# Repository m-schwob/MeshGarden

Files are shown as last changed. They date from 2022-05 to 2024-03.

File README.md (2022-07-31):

# MeshGarden - repository content
The repository contains 3 main folder:
- MeshGardenApp - contains the source good of the android app (built using dart).
- Firbase - contains the source code for firebase cloud functions (written in javaScript).
- ESP - contains the source code for the hardware, ESP32/ESP8266 (written in c++ using arduino framework).

Other useful folders:
- utils - contain some useful code for development but not necessary.
- ESP/examples - contains some side code and example used to develop some of the code unit saperetly. great as code reference.

# MeshGarden - introduction

MeshGarden project is an iot system designed to monitor and maintain small and large scale gardens the system supports a verity of controllers. 
For now its designed to work on ESP8266 and ESP32
the system requires only one ESP32 micro controller to be connected to the Wi-Fi (bridge node) and can maintain many ESP8266 nodes that will take measurements 
from easy to custome sensors.
messages passes down from the sensors to the bridge node via local Mesh network,
the data passes from the bridge node to a firestore server and can be accessed and changed with a designated cell phone app.

# MeshGarden - system diagram

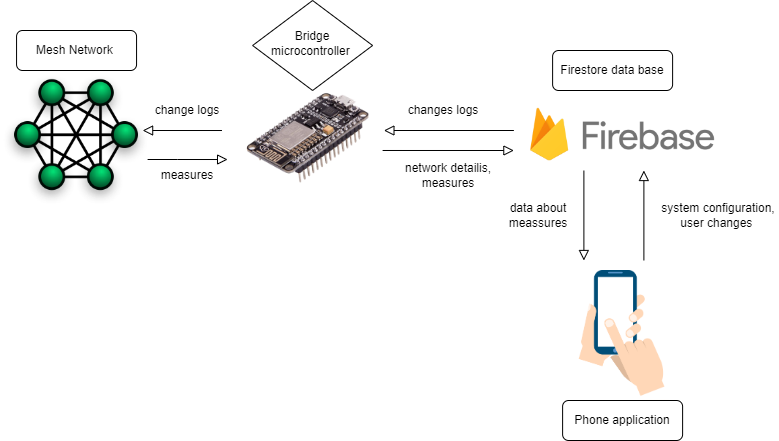
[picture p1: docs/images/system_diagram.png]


As explained, the system composed over 3 major parts: the mesh network , the firestore server and the MeshGarden application 
that are interconnected.

# MeshGarden - nodes life cycle

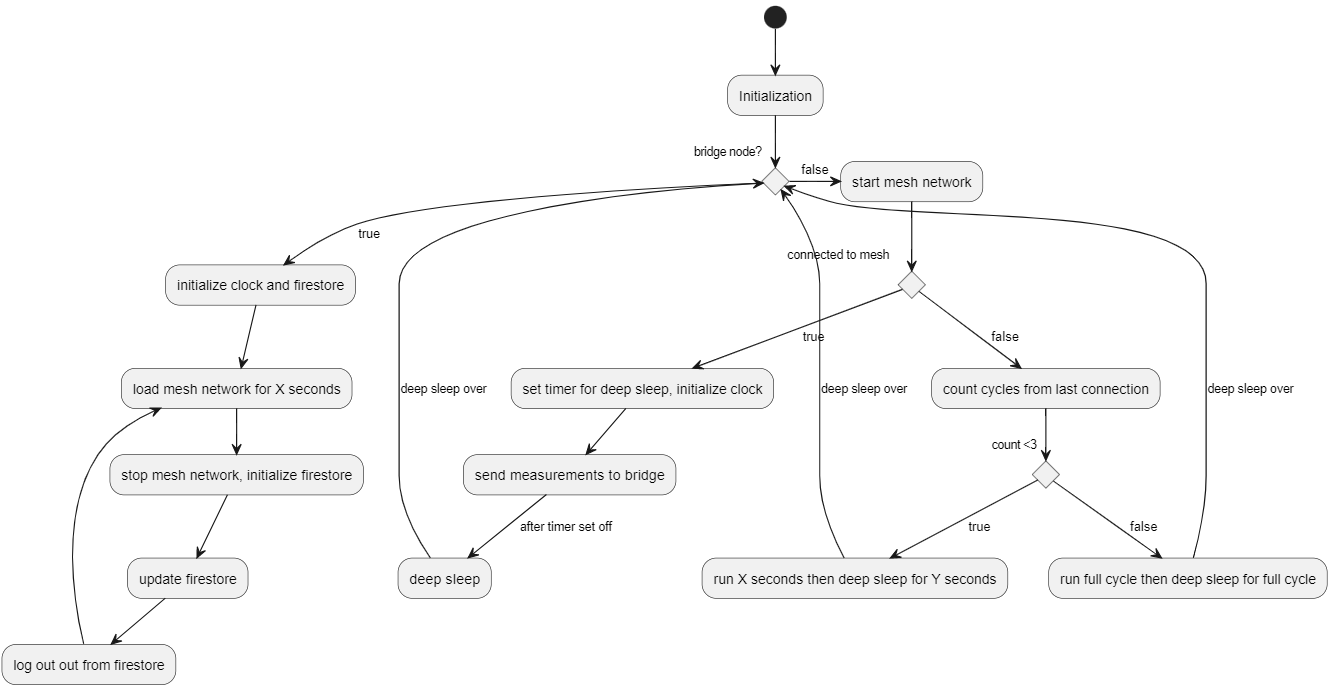
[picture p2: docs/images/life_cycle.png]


# MeshGarden - library dependency

* painlessmesh/painlessMesh@^1.5.0

* mobizt/Firebase Arduino Client Library for ESP8266 and ESP32 @ ^4.0.3

* bblanchon/ArduinoJson @ ^6.19.4

* adafruit/DHT sensor library@^1.4.3

* adafruit/Adafruit ADS1X15@^2.4.0

* me-no-dev/ESP Async WebServer @ 1.2.3

* fbiego/ESP32Time@^1.1.0

# MeshGardenAPP - library dependency
* cupertino_icons: ^1.0.2  
* firebase_auth: ^3.1.0   
* firebase_core: ^1.6.0   
* cloud_firestore: ^3.1.14  
* google_fonts: ^2.1.0    
* adaptive_dialog: ^1.1.0  
* font_awesome_flutter: ^10.1.0  
* chart_sparkline: ^1.0.5  
* intl: ^0.17.0  
* hawk_fab_menu: ^1.1.2  
* flutter_launcher_icons: ^0.9.0  
* charts_flutter: ^0.12.0  
* syncfusion_flutter_charts: 20.1.55  
* syncfusion_flutter_core: 20.1.55  

# MeshGarden - features
Mesh network features:

* Mesh networks allows the user to disperse the sensors over a larger area with no need to be in proximity to Wi-Fi AP
* The system allows the user to add its own costumize sensors easily by writing his own 2 functions
* Mesh networks creates stability, it has the ability to fix itself when a node is down  

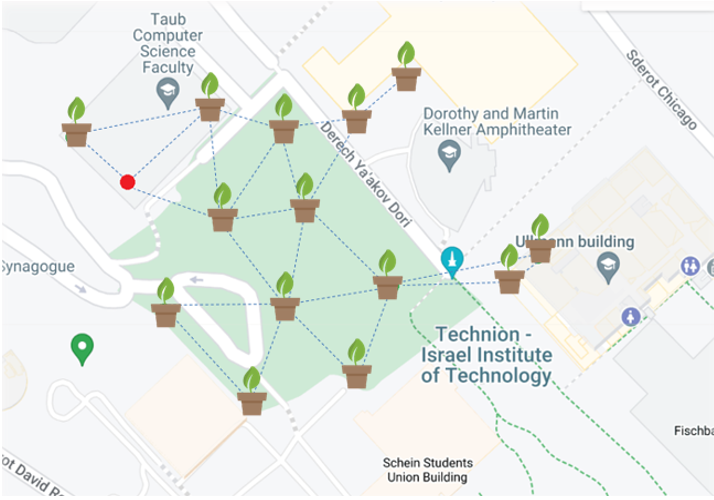
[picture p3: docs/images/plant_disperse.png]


Application features:

* Shows the active nodes in the network
* Change node nicknames of nodes in order to identify where they are located
* Configure new sensors to a node
* Presents the user the measurements of a selected node
* Present the user time series graph of the measures taken by a sensor
* Present the active nodes and their battery values to the user  

App screenshots:

 <table>
  <tr>
    <td>DHT22 Measurements</td>
     <td>UVi and Soli Moisture Measurements</td>
     <td>Time Series chart</td>
  </tr>
  <tr>
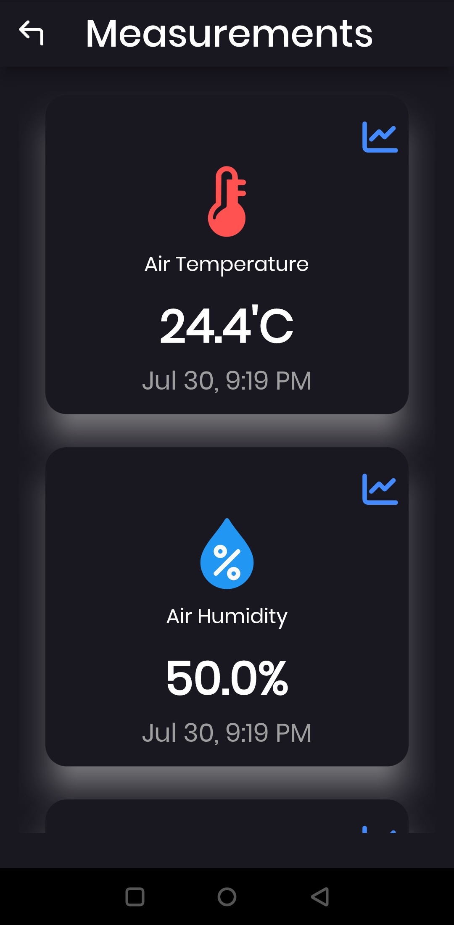
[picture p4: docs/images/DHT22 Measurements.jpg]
    <td valign="top"></td>
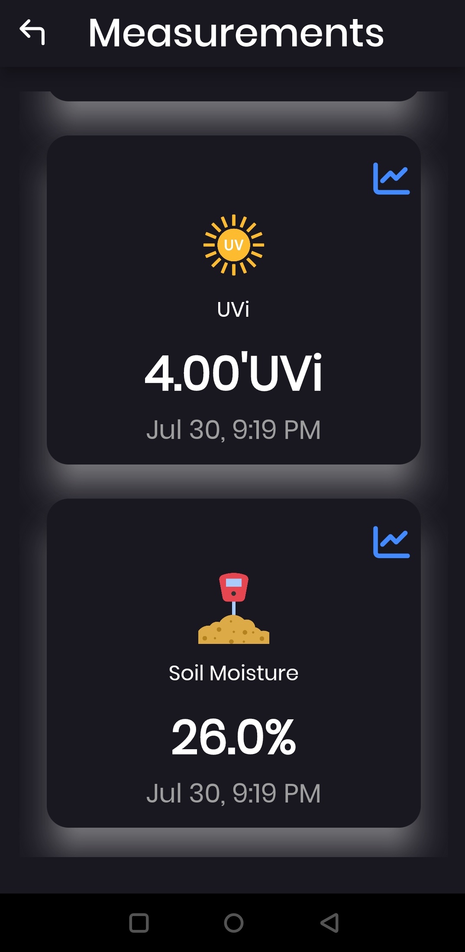
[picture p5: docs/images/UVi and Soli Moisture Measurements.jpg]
    <td valign="top"></td>
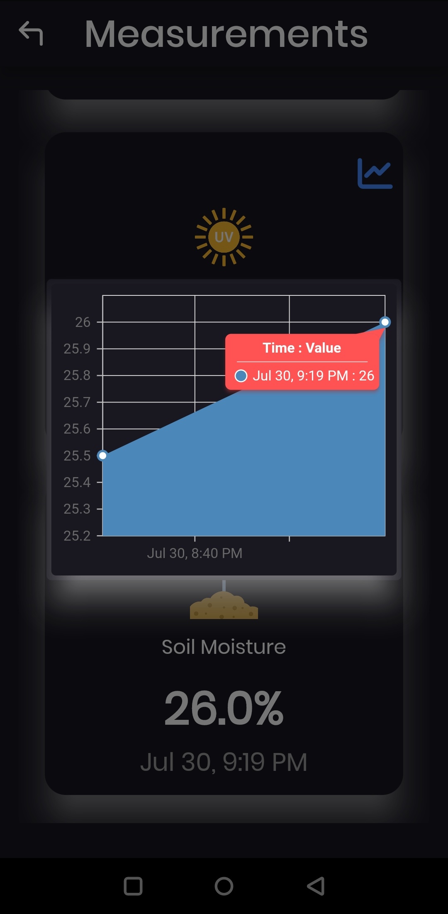
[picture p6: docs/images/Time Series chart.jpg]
    <td valign="top"></td>
  </tr>
 </table>

# MeshGarden - setup the system

## **step 1:** setup firebase server

follow the instruction in the videos bellow by "That Project" in order to setup your own firestore server

video 1:
set a firebase server https://www.youtube.com/watch?v=KV0D8nrsBLg&t=0s  
*TIP* : when choosing the cloud firestore location use the https://www.gcping.com 
site in order to find the server that provide the minimal latency 

video 2:
connect the firebase to the app https://www.youtube.com/watch?v=nsopdabOcug&t=3s   
*Note* : The files provided in the MeshGaredApp directory are source code *only*, so in order to use them,
create a new flutter project and follow the above video  

## **step 2:** create an account in the MeshGarden app with your own usermane and password

## **step 3:** assembly the micro controllers as shown bellow

## **step 4:** prepare the configure.json file

config json for example

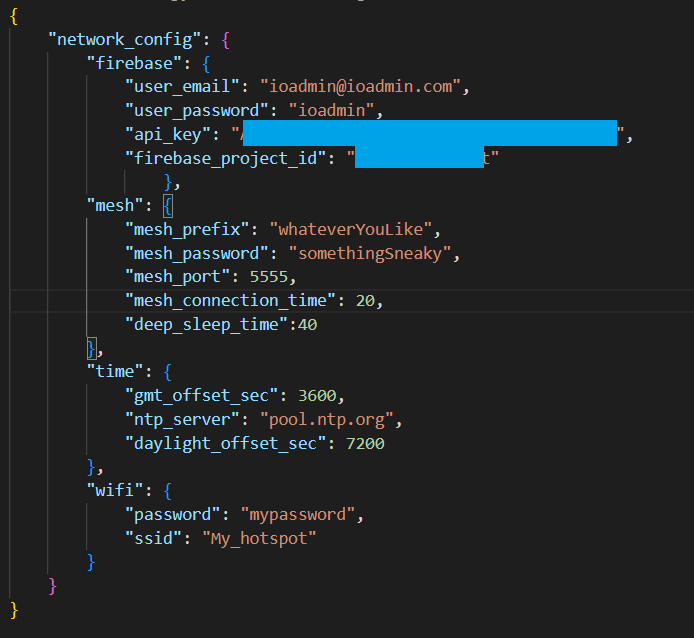
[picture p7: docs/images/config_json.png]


user_email,user_password - the username and password with whom you registered to the application
api_key - the unique key generated for your firebase server
firebase_project_id - the firebase progect id 

**mesh_prefix** - the SSID of the mesh network

**mesh_password** - the Password for the mesh network

**mesh_port** - a port the mesh network will run with

**mesh_connection_time** - the number of seconds within them the mesh network will run and be active (for battery saving for the nodes)

**deep_sleep_time** - the number of seconds withing them all the sensor nodes will go to deep sleep, in that time the bridge connects to the  internet and updates/read the changes from the database

**gmt_offset_sec,ntp_server,daylight_offset_sec**- values set in order to read the current time and make sure the nodes will store the current time in the user region/country

**ssid,password** - the local Wi-Fi ssid and password. Connects the bridge to the internet 

# MeshGarden - Hardware
## Basic Required Hardware

The system must contain at exactly one bridge (ESP32) and at least one node (ESP8266). The bridge is powered by fix power supply since its power consumption is high and can hold for long on battery. The nodes are powered by batteries and to be portable .

## Bridge Components and Assembly:
Components:
- ESP32 micro-controller module
- USB 4V 1A power adapter.
- LED + matched resistor (for example 1.8 green LED with 330ohm resistor)

> The LED use as indicator and connected in parallel to ESP32 module build in LED. So it can be skipped if the build in LED visible.

## Assembly:

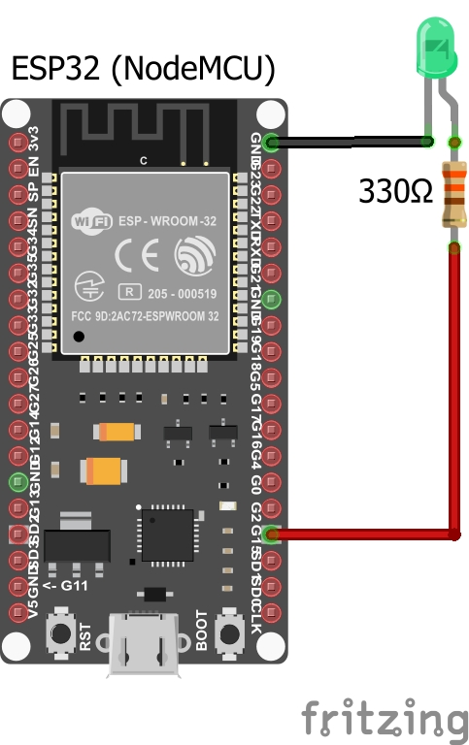
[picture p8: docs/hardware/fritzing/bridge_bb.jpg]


## Node Components and assembly:
Nodes can be assembled in many ways using any sensor. Some component are is required for the system operation and some are optional. The require components are listed in the *Basic Node Module* section below and the optional are exampled in the *Sensors Options* section.

### Basic Node Module
The below component are the base hardware of the node and required for its operations. 

Components:
- ESP8266 micro-controller module
- ADS1115 ADC expender module
- 3.7V lithium battery (2000mAh and greater is recommended)
- TP4056 lithium charging module
- MCP1700-3302E LDO 3.3V voltage regulator
- 100uF capacitor
- 1uF capacitor
- 36k resistor
- 100k resistor
- on/off switch
- NC switch or jumper 
- LED + matched resistor (for example 1.8 green LED with 330ohm resistor)

> all capacitor must be at least 5V rated.

> The LED use as indicator and connected in parallel to ESP8266 module build in LED. So it can be skipped if the build in LED visible.

Assembly:
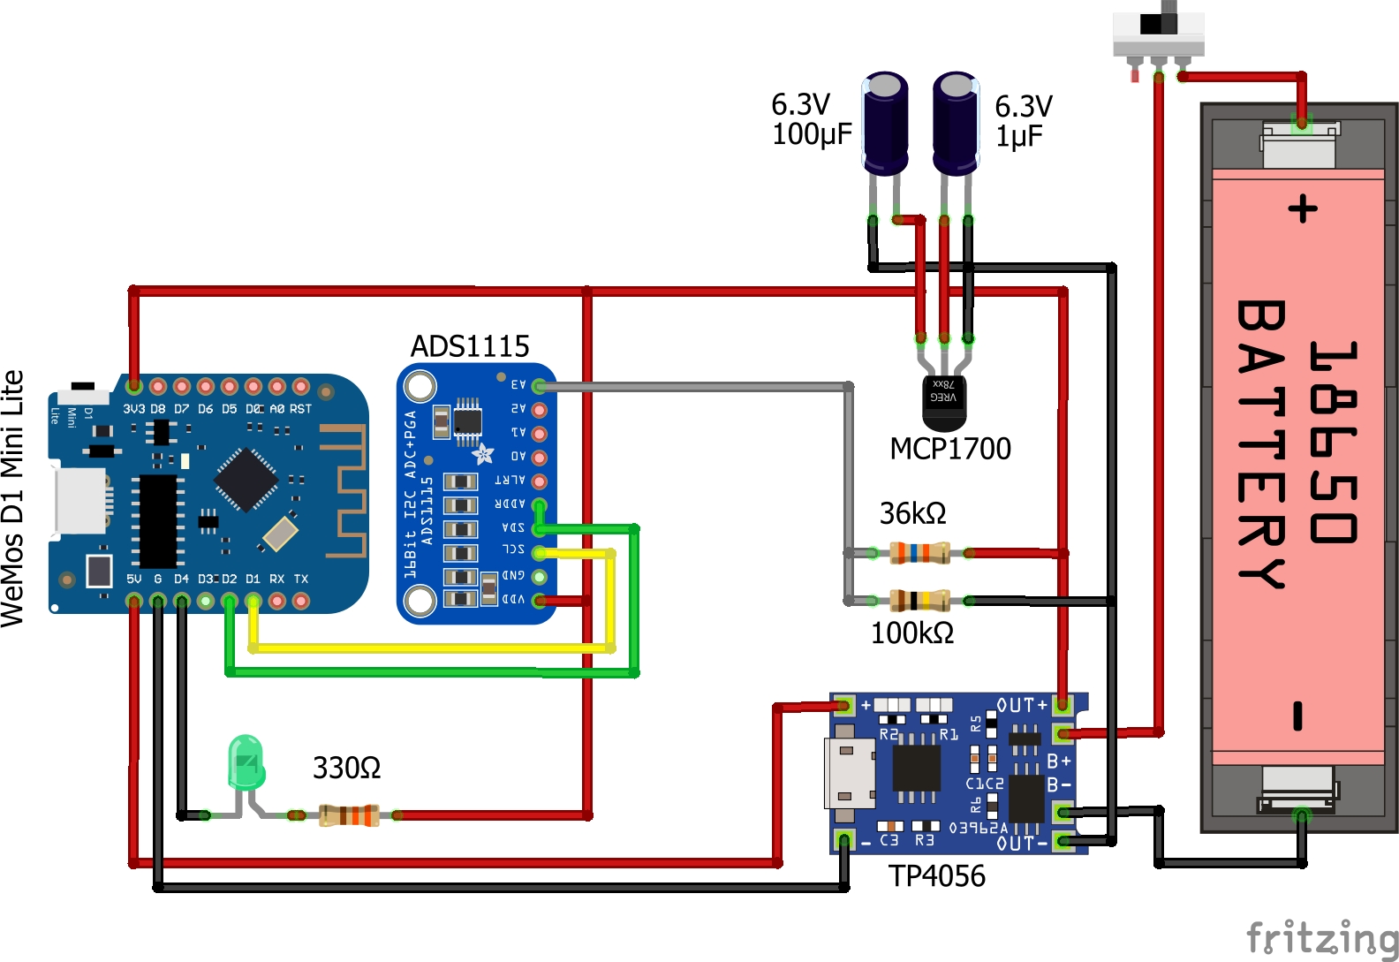
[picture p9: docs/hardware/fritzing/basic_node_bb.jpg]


> the on/off switch (or jumper) required for the micro-controller programming since it cannot be program while D0 and RST pin are connected.

### Sensors Options
After assembling the base node, basically any sensor can be added to the node. the library supports some sensors as build in. Using those sensor require minimal setup without writing any code. Any other sensor will require writing some code and configuration as will be explained later. 

Optional Build in Sensors:
- DHT22 humidly and temperature sensor
- Capacitive soil moisture sensor
- VEML6075 UV sensor

Optional Build in Sensors Assembly (in additional to the Base module!!):
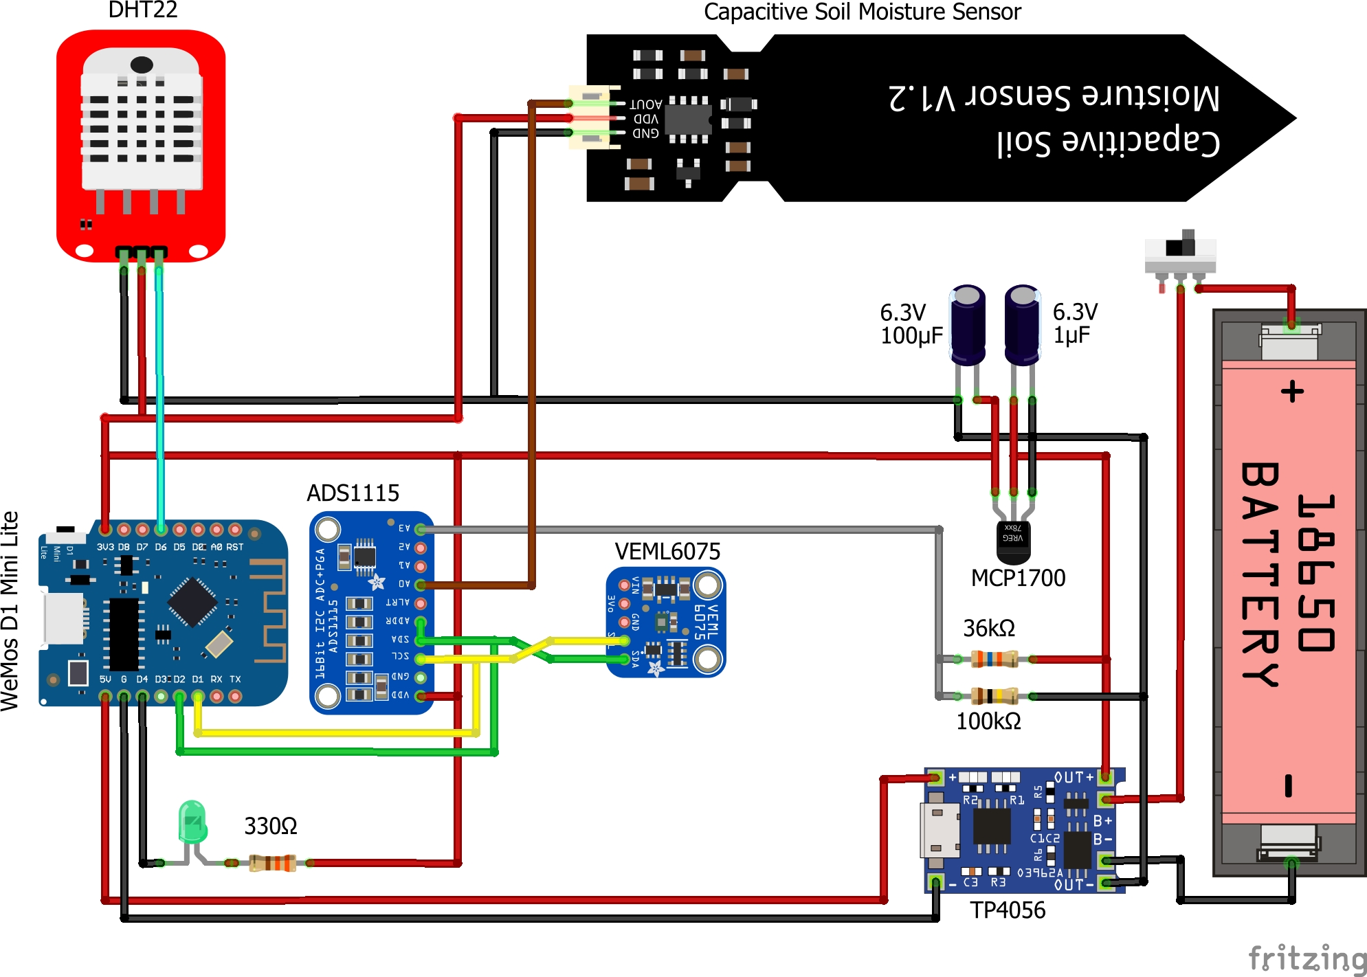
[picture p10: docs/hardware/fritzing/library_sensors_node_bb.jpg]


## make sure to upload the code to the micro controller and connect it to the mesh network

## enter the MeshGarden app find the designated node, and set the sensor as descripted in the pictures bellow

## Note: do not add any sensors to the bridge node 

## BE AWARE: in the type value every new word has to start with a capital letter from A-Z and use underscore " _ " insted of space bar

<table>
  <tr>
    <td>enter the sensors list</td>
     <td>you can choose from prepared sensors or create your own</td>
     <td>set the pins and attributes for your sensor</td>
  </tr>
  <tr>
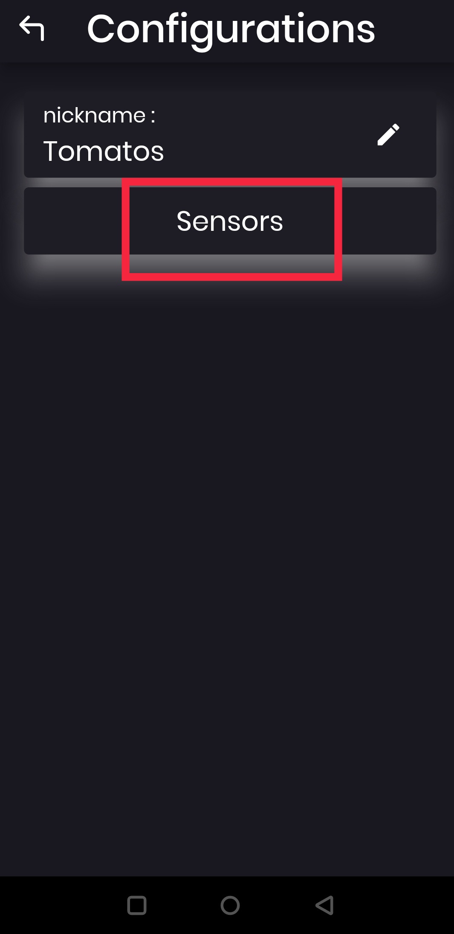
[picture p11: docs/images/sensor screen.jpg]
    <td valign="top"></td>
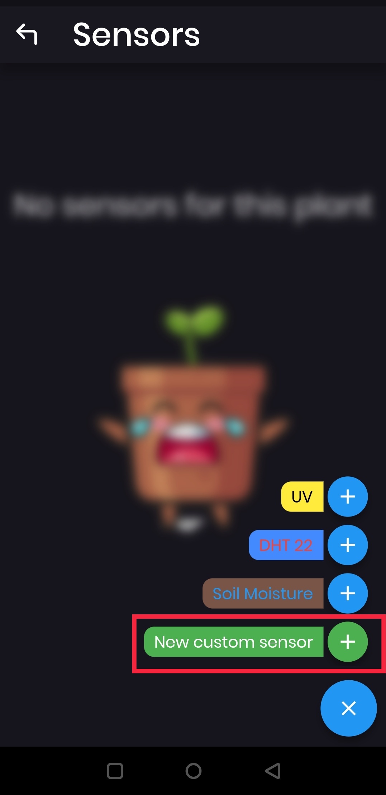
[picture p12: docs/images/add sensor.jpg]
    <td valign="top"></td>
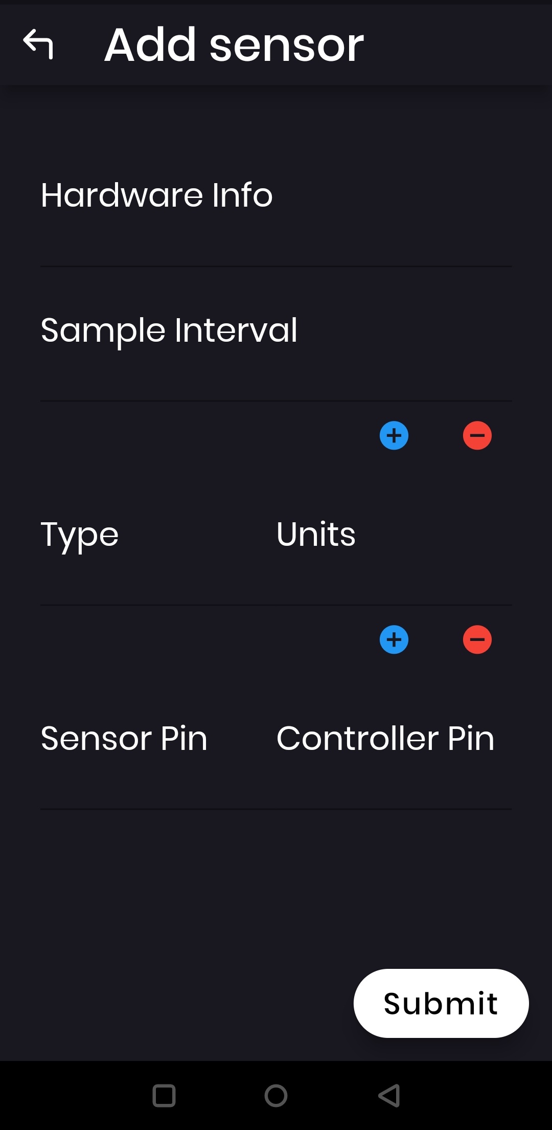
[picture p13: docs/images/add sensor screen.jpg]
    <td valign="top"></td>
  </tr>
 </table>

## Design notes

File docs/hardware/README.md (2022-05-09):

## parts references credits

- https://forum.fritzing.org/t/wemos-d1-mini-lite/11187/7
- https://github.com/OgreTransporter/fritzing-parts-extra
- https://github.com/lambert/fritzing-parts
- https://forum.fritzing.org/t/stepdown-5v-to-3-3v-module/3372/5
- https://github.com/HuangYuTse/DHT22-module-fritzing-part
- https://github.com/adafruit/Fritzing-Library/blob/master/parts/
- https://github.com/robertoostenveld/fritzing
- https://forum.fritzing.org/t/request-18650-battery-holder/4733/4
- https://github.com/mancusoa74/5to3V3DC-DC
- https://forum.fritzing.org/t/ams1117-5v-regulator-module/10547

## sensors:

[soil moisture - opamp version](https://wiki.seeedstudio.com/Grove-Capacitive_Moisture_Sensor-Corrosion-Resistant/)

[ADS1015 with ESP8266 for Multiple Analog Sensors, Analog Extender](https://www.electroniclinic.com/ads1015-with-esp8266-for-multiple-analog-sensors-analog-extender/)

[16-bit, 860-SPS, 4-channel, delta-sigma ADC with PGA, oscillator, VREF, comparator and I2C](https://www.ti.com/product/ADS1115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)

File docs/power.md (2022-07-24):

- seems that on board regulator not nessccery LDO and may not fit power requirements.
- make table for the popular boards and compare regulator (max current (and max current), voltage range, power drop)
- make table of comparing solutions - efficiency, life time, complexity.
- the idea is to separate power module from controller. the interface is with 2 option 3.3/5V like most boards. the specific solution will mke sure the right voltage 

** base configuration is 3.3V direct to chip or 5 volt via LDO. **
    - micro usb on board connected to 5V and data.
    - pro configuration use the on board regulator.

- think how to configure voltage rang. maybe one user config and second using build in input measurement

options:
1. base and simple - use replaceable battery (3 AAA batteries, or lithium). connect to 5V input
2. lithume with cnargingg module
3. direct wall adpater standart usb
4. solar panel/wind turbine with batteries or capacitor

-pro: you can make uredelf that make sure voltage and corrent range

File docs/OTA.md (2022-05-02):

# OTA
 Write sometion about the idea and bring the concept drawing. Say what we will  inplement now 

>CI/CD is a method to frequently deliver apps to customers by introducing automation into the stages of app development. The main concepts attributed to CI/CD are continuous integration, continuous delivery, and continuous deployment.
> See [What is CI/CD? Continuous integration and continuous delivery explained][What is CI/CD? Continuous integration and continuous delivery explained]
 -(I didnt really went into it but got the general idea and it looks like good source to start with)

Write the requirements.

Write the steps by the github to firebase guide and then the arduino code side. Finelly the firebase side.

Write about futer option such build on github action.

### References
[Test compile for Arduino](https://github.com/marketplace/actions/test-compile-for-arduino)
> Referenced from [Arduino Builder on Github Action](https://github.com/marketplace/actions/run-arduino-builder)

[Upload a file in the repository to Firebase Storage in Github Action](https://quandnl.medium.com/upload-files-in-repository-to-firebase-storage-in-github-action-f467c1309a54)

[]()

[]()

[]()

[]()

[What is CI/CD? Continuous integration and continuous delivery explained](https://www.google.com/amp/s/www.infoworld.com/article/3271126/what-is-cicd-continuous-integration-and-continuous-delivery-explained.amp.html)

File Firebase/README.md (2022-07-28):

## environment tools

run all commands in powershell
there may be issue with firestore command in powershell. there is solution one of those command
 Set-ExecutionPolicy -ExecutionPolicy RemoteSigned -Scope menas
 Set-ExecutionPolicy -ExecutionPolicy RemoteSigned -Scope CurrentUser

### environment setup

links:
https://codewithandrea.com/articles/firebase-cloud-functions/
https://jsmobiledev.com/article/firebase-emulator-guide/
https://jsmobiledev.com/article/firebase-emulator/

- install node.js

npm install -g firebase-tools

firebase login  
firebase init      
firebase deploy --only functions

firebase init emulators
firebase emulators:export emulator_ex_data
firebase emulators:start --import emulator_ex_data_db

### import/export from production database

npm install -g node-firestore-import-export

firestore-export --accountCredentials meshgarden-iot-firebase-adminsdk-o9fjg-0ca4c4061f.json --backupFile firestore_seed.json
firebase emulators:start --only firestore
$env:FIRESTORE_EMULATOR_HOST = "0.0.0.0:8080"
firestore-import --accountCredentials meshgarden-iot-firebase-adminsdk-o9fjg-0ca4c4061f.json --backupFile firestore_seed.json
firebase emulators:export emulator_ex_data_db

### kill port tool
npm install --global kill-port
kill-port --port 8080

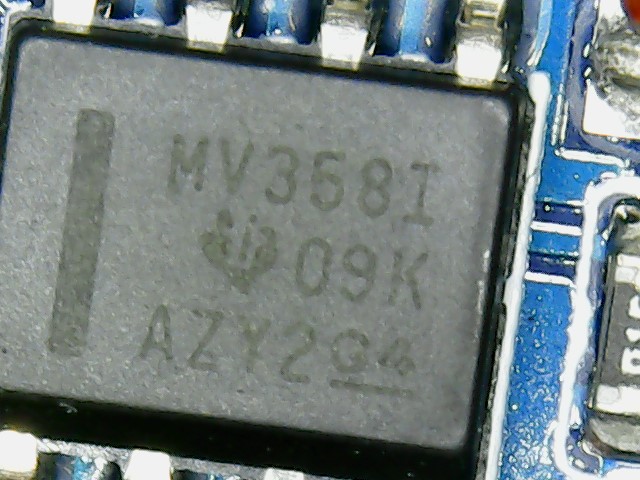
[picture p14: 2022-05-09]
docs/hardware/soil_sens_opamp.jpg

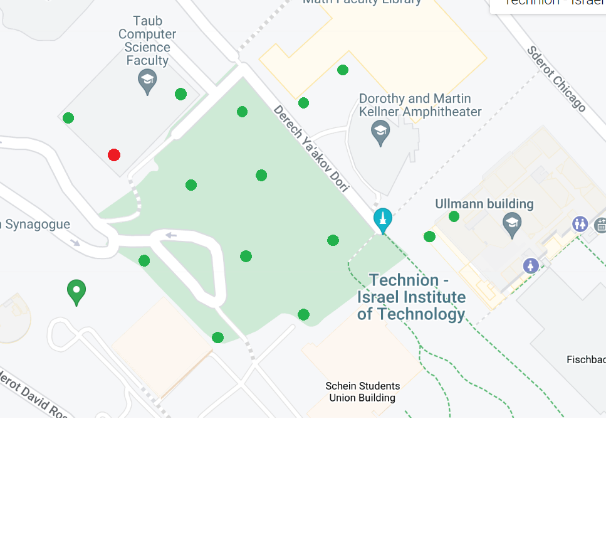
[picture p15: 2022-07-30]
docs/images/node_dispursal_simolation.png

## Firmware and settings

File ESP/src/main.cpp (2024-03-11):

#include <Arduino.h>
#include <ArduinoJson.h>
#include "mesh_garden.h"

#if defined(ESP8266)
ADC_MODE(ADC_VCC); // enable measure esp8266 supply input voltage
#endif

/*
This documentation will be after use for user instruction and documentation. but for now its here to simplify.

For custom sensor, user need to provide the following information:
- A function in the .ino file that know how to init the sensor (called one time when the system boot up)
- A function in the .ino file that know how to handle the measuring proccess and return the measured value in the correct units.
    - To support sensor that measure more then one value the return value must be an array. The array will use Measurement type.
- An hardware id that will also add to the app. (that will be used to init the correct sensor in run time).
- A information that will be add via the app (option for json file?):
    - hardware id - short String that uniquely represent the sensor. must matched the hardware id mentioned before.
    - pinout - the how the sensor connected to the board. for example if pin 'DAT' of the sensor connected to pin 'D1' of the
                 board, both values will linked via the app and in the above functions it will be use using pin(Sting pin_name)
                 function, for example: pinMode(pin("DAT"), INPUT), readDigital(pin("DAT")).
    - measurement_types - a list of Strings. each represent one measurement type to handle multi measurements sensors.
    - units - a list of Strings. units of each measurement_type.
    - time_interval - the time intervale between preformed measurements

For the .ino file, he idea is to give the user two way of adding his own sensor:
1. Beginners options - implementing two functions 'void init_sensor()' and 'Measurement measure()' and registering the sensor using
    provided library function 'add_sensor(String hardware_id, InitFunc init_sensor_func, MeasureFunc measure_func)'.
    (that will make a class in the background)
2. Advanced options - making a custom class inheriting the sensor class and implementing the above functions and registering the sensor
        using. This option gives user more power to override default behaviors. (consider supporting this for this project)

*/

#define BAUD_RATE 115200

/*************** CLASS EXAMPLE ****************** /
Define sensor using class example.
Capacitance soil moisture sensor using ADS1X15 ADC extender.
*/

#include <Adafruit_ADS1X15.h>
#include <SPI.h>
#include "Device.h"
#include "Sensor.h"

#define _DEVICE_TYPE "Soil Moisture Sensor"
#define _HARDWARE_INFO "Groove Soil Moisture"
#define _MEASUREMENTS_TYPE "Soil Moisture"
#define _UNITS "%"

class SoilMoistureSensorGroveV1 : public Sensor
{
private:
    uint8_t analog_pin = 0;

    float C_air = 2.2; // volts
    float C_water = 1; // volts

    // ADS1X15 related. TODO make driver for it. check example file
    Adafruit_ADS1115 _ads;

    void init_adc()
    {
        _ads.setGain(GAIN_ONE);
        if (!_ads.begin(0x4A))
        {
            Serial.println("Failed to initialize ADS.");
        }
        else
            Serial.println("ADS initialized");
    }

    float extender_measure(uint16_t pin)
    {
        int16_t adc0 = _ads.readADC_SingleEnded(pin);
        float volts0 = _ads.computeVolts(adc0);
        Serial.println("extender measure"); // TODO print value
        return volts0;
    }

    float percentage(float value, float max, float min = 0)
    {
        if (min > value || value > max)
            return -1;
        return (value - min) / (max - min);
    }

public:
    SoilMoistureSensorGroveV1(DEVICE_CONSTRUCTOR_ARGUMENTS)
        : Sensor(device_id, hardware_info, pinout, envelop)
    {
        init_adc();                                               // ADS1X15 related.
        Serial.printf("%s: initalized\n", HARDWARE_INFO.c_str()); // add details about pins i.e.
    }

    Measurements measure()
    {
        Measurements measurements(1);
        Measurement moisture;
        moisture.type = "Soil Moisture";

        float volt = extender_measure(analog_pin);
        // TODO handle the case that the value go off range
        moisture.value = 1 - percentage(volt, C_air, C_water);
        measurements.push_back(moisture);
        Serial.printf("%s: measure %f volts, %f/1 range\n", HARDWARE_INFO.c_str(), volt, moisture.value);
        return measurements;
    }

    void calibrate() { calibrated = true; }
};

REGISTER_DEVICE(SoilMoistureSensorGroveV1, "Grove Soil Moisture Sensor v1");

/*****************************************************/

/****************** FUNCTIONS EXAMPLE ********************* /
Define sensor using functions example.
DHT22 air humidity and temperature sensor.
*/
#include <DHT_U.h>
#define DHTPIN 2
#define DHTTYPE DHT22

DHT dht(DHTPIN, DHTTYPE);

/* create  two functions */
void init_DHT()
{
    dht.begin();
    Serial.println(F("DHT22 initialized"));
}

Measurements measure_DHT()
{
    // Reading temperature and humidity
    float h = dht.readHumidity();
    float t = dht.readTemperature();

    if (isnan(h) || isnan(t) || isnan(f))
    {   // Check if any reads failed 
        Serial.println(F("Failed to read from DHT sensor!")); 
    }

    Measurements measurements(2);
    Measurement temperature;
    Measurement humidity;

    temperature.type = "Temperature";
    temperature.value = t;
    measurements.push_back(temperature);

    humidity.type = "Humidity";
    humidity.value = h;
    measurements.push_back(humidity);

    return measurements; // temporary for compiling
}

/* register your sensor */
REGISTER_SENSOR("DHT22 Sensor");  

MeshGarden garden;

void setup()
{
    Serial.begin(115200);
    Serial.println();

    /* register your functions */
    garden.add_sensor("DHT22 Sensor", init_DHT, measure_DHT);
    garden.begin();

    Serial.println("printing device list");
    for (String device : garden.get_device_list())
    {
        Serial.println(device);
    }
}

void loop()
{
    garden.update();
}

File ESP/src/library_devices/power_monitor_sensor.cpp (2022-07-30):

#include "library_devices/power_monitor_sensor.h"

const float PowerMonitorSensor::full_voltage = 4.2;  // volts
const float PowerMonitorSensor::drained_voltage = 3; // volts
const int PowerMonitorSensor::map_steps = 13;
const float PowerMonitorSensor::map_step = 0.1;
const int PowerMonitorSensor::capacity_map[map_steps] = {0, 1, 2, 5, 13, 22, 39, 53, 62, 74, 84, 94, 100};

// battery  is not linear. estimate ther percentage with the help of the capacity map
//return 0-100 float value
float PowerMonitorSensor::calculate_percentages(float voltage)
{
    float index = (voltage - drained_voltage) / map_step;
    int upper_index = ceil(index) >= map_steps? map_step: ceil(index);
    int lower_index = floor(index) < 0? 0: floor(index);

    Serial.println("PowerMonitorSensor: indexes-> i-" + String(index) + ", u-" + String(upper_index) + ", l-" + String(lower_index));
    // linear calculation between map indexes values
    return capacity_map[lower_index] + (index - lower_index) * (capacity_map[upper_index] - capacity_map[lower_index]);
    // return 0.5 * (capacity_map[lower_index] + capacity_map[upper_index]); // avg: lower + (upper-lower)/2 => 0.5*lower + 0.5*upper => 0.5*(upper+lower)
}

// measured voltage (VOUT) is not the real battery voltage since there is voltage divider
// VBAT -> R1 -> VOUT -> R2 -> GND
// TODO check if input voltage ha effect on measurement
float PowerMonitorSensor::real_voltage(float VOUT)
{
    float R1 = 36000.0, R2 = 100000.0; // ohm
    float _real_voltage = (1 + R1 / R2) * VOUT;
    // Serial.println("VOUT: " + String(VOUT) + " real voltage calculated: " + String(_real_voltage));
    return _real_voltage;
}

PowerMonitorSensor::PowerMonitorSensor(DEVICE_CONSTRUCTOR_ARGUMENTS)
    : Sensor(device_id, hardware_info, pinout, envelop)
{
    if (pinout.containsKey("BAT"))
        analog_pin = pin(pinout["BAT"].as<String>());
    else
    {
        Serial.print(HARDWARE_INFO.c_str());
        // TODO consider not setting default pin but disabling it
        Serial.println(":Warning: sensor pin not defined. set to 0 as default");
    }
}

Measurements PowerMonitorSensor::measure()
{
    String s = HARDWARE_INFO + ": ";
// until i will find esp32 equivalent for ESP.getVcc()
#if defined(ESP8266)
    Measurements measurements(3);

    Measurement input_voltage;
    input_voltage.type = INPUT_VOLTAGE_KEY;
    input_voltage.value = ESP.getVcc() / 1000; // getVcc return voltage in mV
    measurements.push_back(input_voltage);

    s += "input voltage " + String(input_voltage.value) + "V, ";
#else
    Measurements measurements(2);
#endif

    float volt = analog_read(analog_pin);

    Measurement battery_voltage;
    battery_voltage.type = BATTERY_VOLTAGE_KEY;
    battery_voltage.value = real_voltage(volt);
    measurements.push_back(battery_voltage);

    Measurement battery_level;
    battery_level.type = BATTERY_LEVEL_KEY;
    battery_level.value = calculate_percentages(battery_voltage.value); // TODO calculate by non linear graph
    measurements.push_back(battery_level);

    s += "battery voltage " + String(battery_voltage.value) + "V, " +
         "battery level " + String(battery_level.value) + "%";
    Serial.println(s);
    return measurements;
}

void PowerMonitorSensor::calibrate() { calibrated = true; }

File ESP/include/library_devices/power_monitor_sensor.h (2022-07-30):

#ifndef _BATTERY_LEVEL_SENSOR_H_
#define _BATTERY_LEVEL_SENSOR_H_

#include <ArduinoJson.h>
#include "constants_utils.h"
#include "pins_maps.h"
#include "sensor.h"

// ADC_MODE(ADC_VCC); // enable measure esp8266 supply input voltage

#define BATTERY_LEVEL_KEY "Battery Level"
#define BATTERY_VOLTAGE_KEY "Battery Voltage"
#define INPUT_VOLTAGE_KEY "Input Voltage"

class PowerMonitorSensor : public Sensor
{
private:
    uint8_t analog_pin = 0;

    static const float full_voltage;    // volts
    static const float drained_voltage; // volts
    static const int map_steps;
    static const float map_step;
    static const int capacity_map[];

    static float calculate_percentages(float voltage);
    static float real_voltage(float voltage);

public:
    PowerMonitorSensor(DEVICE_CONSTRUCTOR_ARGUMENTS);
    Measurements measure();
    void calibrate();
};

// REGISTER_DEVICE(PowerMonitorSensor, "Battery Level Sensor");

#endif /* _BATTERY_LEVEL_SENSOR_H_ */

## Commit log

2022-04-29 add frizing connections diagram
    [base_version.fzz]
2022-05-02 move mesh samples
2022-05-02 Add files via upload
    added mesh garden app ,and dht11+firestore for esp32
2022-05-02 add ESP32 board config
2022-05-04 ideas for power solutions
2022-05-06 add skeleton of device and sensor classes
2022-05-08 tamp power_pin timing bug fix
2022-05-09 add main.cpp as test for siol musture sensor
2022-05-09 fix file extention missing
    [mesh_node.cpp]
2022-05-09 still not working :(
    [mesh_node.cpp]
2022-05-09 samples nodes
2022-05-09 prepare for sensor integration
2022-05-10 function sending solved. NOTE this is temporary commit and some fixes to the code is needed. look later on changes
    [main.cpp, mesh_node.cpp]
2022-05-12 implement sensor class. cannot solve undefined reference error
2022-05-13 add device class and make sensor class inherit from it
2022-05-15 base prototype works with uploading to server
2022-05-16 add data to sensor in the diagram and addd support for multiple measurement types in same sensor
2022-05-17 start adding nultiple measurement type to sensor. TBD
2022-05-17 add sensor_id varible to Measurment
2022-05-17 firestore active node works, samples in comment
2022-05-18 add support for multi measurments types sensors
2022-05-18 add init example for dummy sensor
2022-05-28 parsing pre loaded config json and print it to consol
2022-05-28 print memory usage information. change json init size to file size
2022-05-29 create and test DeviceFactory.
2022-05-29 add device factory to main project
2022-05-30 Revert "befor merge"
    This reverts commit b81bee0877d737284a8e82be5506810c60df28ff.
    [mesh_bridge.cpp]
2022-06-01 update device factory constructor to match device constructor
2022-06-01 ad pins maps. stack into multiple definition compilation error
    [main.cpp, mesh_garden.cpp, pins_maps.cpp]
2022-06-03 update pins map size calculation and update printed information
2022-06-05 remove get_values func from sensor
2022-06-05 add generic senssor in mesh_garden ro sopport esy sensor adding
2022-06-05 refactor device and sensor classes for the new design
2022-06-05 add generic sensor to support easy custom sensors. rewrite parsing to support it and to match the design changes
2022-06-06 first attampt for fix. waiting for availiable esp32 for testing
2022-06-12 ini small fix. add comment in main
    [main.cpp]
2022-06-20 fix power check pin in device
    [device.cpp]
2022-06-20 fix littlefs for esp32
    [partitions_custom.csv]
2022-06-20 bug fixes in generic sensor, device envelop creating, mesh garden config json loading, soil moisture class
    [device.cpp, main.cpp, mesh_garden.cpp]
2022-06-20 bring littlefs esp32 fix
    [partitions_custom.csv]
2022-06-20 ignore imupdated files in compilation. start adding network initilize to mesh garden
2022-06-23 getting node sensors ids
2022-06-23 getting measurement sensor ids
2022-06-24 Added sensor measurements model, updated Measurements screen, Added "wifi" icon to bridge node, Added measurements card
2022-06-25 Added image to measures, Added new consts, Added battery to nodes
2022-06-25 syncro done prototype
2022-06-25 partly start to create battery sensor ad ads1115 class
2022-06-25 fix reading config bugs
    [mesh_bridge.cpp, mesh_garden.cpp, mesh_node.cpp]
2022-06-25 sync tests keep a queue of samples
2022-06-25 load and store node time when die
2022-06-25 add ADS to mesh garden class. create functionalitiy to easy measure from any code. add ADS pins to mins map. add power on/off to sensor measure wrap function
2022-06-25 add power monitor sensor
2022-06-25 Added date time display to measurements, Removed unnecessary configurations, Added default sensors choose
2022-06-25 add power mpnitor sesnor to mesh garden class
2022-06-25 Changed sensors display cards and custom sensor display
2022-06-25 not working network, not getting eifi
    [mesh_bridge.cpp, mesh_node.cpp]
2022-06-25 try to solve includes cycle issue but run into multi definition issue
    [power_monitor_sensor.h]
2022-06-26 battery voltage measure work but battery level calculation still wrong
    [power_monitor_sensor.cpp]
2022-06-26 need to fix measuremennts
    [mesh_bridge.cpp, mesh_node.cpp]
2022-06-26 fix battery level claculation. use capacity map and take in account voltage divider
    [power_monitor_sensor.cpp, power_monitor_sensor.h]
2022-06-26 prototype of mesh connection
2022-06-26 Added samples check and units according to each type
2022-07-18 fixed some things about the bridge and nodes
    [mesh_bridge.cpp, mesh_node.cpp]
2022-07-23 add servo examle
2022-07-24 fix power monitor code does not fit esp32
    [main.cpp, mesh_garden.cpp, power_monitor_sensor.cpp]
2022-07-24 fix esp32 crashes from ads. integration with sync
    [main.cpp, mesh_bridge.cpp, mesh_node.cpp]
2022-07-28 calculation fixed and improved
    [power_monitor_sensor.cpp]
2022-07-28 added prints for safety
2022-07-28 add Soil muistor sensor to library sensors
2022-07-28 minor fixes include format style. .ini move firebase library to esp8266 envirument to reduce compile time
    [main.cpp, power_monitor_sensor.cpp, power_monitor_sensor.h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]
2022-07-28 replace ADS1X15 constructor with begin fonction
    [mesh_garden.cpp]
2022-07-28 PowerMonitorSensor add index limit to prevent getting grabage values if there is measrement error
    [power_monitor_sensor.cpp]
2022-07-28 Changed sensors map name to "sensor.{sensor_id}"
2022-07-28 Changed "UV" sensor label color to black
2022-07-29 firebase functions: fix Nodes onChange to preform action only if 'sensors' field has change and write only neccery data to config
2022-07-29 add uvi sensor class
2022-07-29 add DHT22 sensor to library sensors
2022-07-29 fix add calibration function to DHT22
    [DHT22_sensor.cpp]
2022-07-29 remove old dummy sensors files
2022-07-29 Library sensors update, changed dht11 header to "DHT22", Added Measuresdata model, Added chart to measurements
2022-07-30 fixed bridge sends measures, added time diff function in node
    [mesh_bridge.cpp, mesh_garden.cpp, mesh_node.cpp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]
2022-07-30 set interval for not connecting in node, few fixes for measurements
    [mesh_bridge.cpp, mesh_garden.cpp, mesh_node.cpp]
2022-07-30 fixed timing issues between nodes and bridge
    [mesh_bridge.cpp, mesh_garden.cpp, mesh_node.cpp]
2022-07-30 fixed time for read to the server
    [mesh_node.cpp]
2022-07-30 fixed timing and sleep times as agreed
    [mesh_bridge.cpp, mesh_node.cpp]
2022-07-30 adding assambly picture
    [basic_node.fzz, bridge.fzz, library_sensors_node.fzz]
2022-07-30 bridge map key value fix
    [mesh_bridge.cpp, mesh_node.cpp, soil_moisure_sensor.cpp]
2022-07-30 fix if defined ..
    [mesh_garden.cpp, soil_moisure_sensor.cpp]
2022-07-31 add light indicator for error in time read fron ntp req
    [mesh_bridge.cpp, mesh_node.cpp]
2022-07-31 reorgnize file system
    [partitions_custom.csv]
